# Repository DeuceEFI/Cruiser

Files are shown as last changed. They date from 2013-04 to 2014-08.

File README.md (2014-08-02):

# Cruiser Development Board for FreeEMS

JAG 8/2/2014 1422 EDT (GMT-0400)

### Introduction

The name "Cruiser" is loosely based on the SanDisk Cruzer Edge USB flash drive that was sitting in front of me while I was designing this development board.  This is intended to be a handy, portable, USB bus powered development board for Freescale MC9S12XDP512 firmware and software developers.

Please see forum.diyefi.org for the most up to date information and links for this project and all of the other aspects of the FreeEMS project.

### Goals

Core specs:

 * The least amount of parts to make a functional development board.
 * Freescale MC9S12XDP512MAL processor with 16MHz crystal.
 * FTDI USB (bus powered) communications (USB-A board edge connector).
 * Rx/Tx LEDs for USB communications troubleshooting.
 * Load/Run LED connected to Port A6.
 * Solder bridge pads for enabling LEDs.
 * Reset momentary switch.
 * Load momentary switch.
 * Port T0-3 inputs/outputs with 1k current limiting resistors.

PCB size is to be as small as possible and to be powered by the USB bus, to allow for easy transport for development work.  The current design is a 50mm x 50mm PCB (shaped like a key) which has an USB-A male connector.  There are solder bridge pads on the bottom layer to allow the LEDs to be connected or not, depending on whether the user would like the LEDs for troubleshooting or stealth.
 
### Status

This design has been tested and is considered to be a usable design.

I will update this status as work progresses.

#### Update 11/15/2012: The first 10 version 0.1-alpha PCBs have been ordered from seeedstudio Fusion PCB service for testing the design.

#### Update 8/2/2014: I now stock the 0.3-alpha PCBs and components, they can be ordered from http://www.coolefi.com

### Changes

Please send any changes that you make to Cruiser back upstream to Andy Goss' copy at https://github.com/DeuceEFI/Cruiser

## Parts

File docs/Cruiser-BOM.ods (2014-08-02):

Quantity | Reference | Value | Description | Manufacturer | Manufacturer Part # | Digikey Part # | Approximate Cost Each | Cost to Build
3 | C1,2,3 | 0.1uF | Ceramic Capacitor 0.1uF 50V 10% X7R 1206 | Kemet | C1206C104K5RACTU | 399-1249-1-ND | $0.10 | $0.30
7 | C4,5,6,7,8,9,10 | 0.22uF | Ceramic Capacitor 0.22uF 50V 10% X7R 1206 | Samsung Electro-Mechanics | CL31B224KBFNNNE | 1276-1106-1-ND | $0.05 | $0.35
1 | C11 | 10uF | Ceramic Capacitor 10uF 16V 10% X7R 1206 | Kemet | C1206C106K4RACTU | 399-3525-1-ND | $0.40 | $0.40
2 | C12,13 | 18pF | Ceramic Capacitor 18pF 50V 10% NP0 1206 | Kemet | C1206C180J5GACTU | 399-1195-1-ND | $0.13 | $0.26
1 | C14 | 6.8nF | Ceramic Capacitor 6800pF 100V 5% X7R SMD 1206 | AVX | 12061C682JAT2A | 478-3794-1-ND | $0.27 | $0.27
1 | C15 | 680pF | Ceramic Capacitor 680pF 630V 5% NP0 1206 | TDK Corporation | C3216C0G2J681J085AA | 445-2341-1-ND | $0.28 | $0.28
1 | D2 | Green LED | LED 568NM Green SMD 1206 | OSRAM Opto Semiconductors | LG N971-KN-1 | 475-1407-1-ND | $0.09 | $0.09
1 | D3 | Red LED | LED 645NM Red SMD 1206 | OSRAM Opto Semiconductors | LH N974-KN-1 | 475-1416-1-ND | $0.09 | $0.09
1 | D1 | Yellow LED | LED 587NM Yellow SMD 1206 | OSRAM Opto Semiconductors | LY N971-HL-1 | 475-2556-1-ND | $0.11 | $0.11
1 | L1 | 40 | Ferrite 1.5A 40 Ohm 0805 SMD | Laird-Signal Integrity Products | MI0805K400R-10 | 240-2389-1-ND | $0.10 | $0.10
6 | R1,2,3,4,5,6 | 10k | Resistor 10K Ohm 1/4W 1% 1206 SMD | Bourns | CR1206-FX-1002ELF | CR1206-FX-1002ELFCT-ND | $0.02 | $0.12
8 | R7,8,11,12,13,14,15,16 | 1k | Resistor 1.0K Ohm 1/4W 5% 1206 SMD | Panasonic Electronic Components | ERJ-8GEYJ102V | P1.0KECT-ND | $0.02 | $0.19
1 | R10 | 3.3k | Resistor 3.30K Ohm 1/4W 1% 1206 SMD | Yageo | RC1206FR-073K3L | 311-3.30KFRCT-ND | $0.03 | $0.03
2 | SW1,2 | Load,Reset | Tactile Switch SPST-NO 0.05A 12V | APEM Components | MJTP1230 | 679-2428-ND | $0.10 | $0.20
1 | U1 | FT232RL | IC USB FS Serial UART 28-SSOP | FTDI | FT232RL-REEL | 768-1007-1-ND | $4.05 | $4.05
1 | U2 | MC9S12XDP512 | IC MCU 512K Flash 112-LQFP | Freescale | MC9S12XDP512MAL | MC9S12XDP512MAL-ND | $23.51 | $0.00
1 | X1 | 16MHz | Crystal 16.000MHz 18pF 4-SMD | CTS-Frequency Controls | 405C35D16M00000 | CTX820CT-ND | $1.16 | $1.16
1 | USB-A |  | USB-A Male Connector | CNC Tech | 1001-010-01001 | 1175-1007-ND | $0.65 | $0.65
1 | PCB |  | Cruiser Printed Circuit Board | SeeedStudio Fusion PCB |  | Approximate Cost |  | $1.40
 |  |  |  |  |  | Total Cost To Build |  | $10.05

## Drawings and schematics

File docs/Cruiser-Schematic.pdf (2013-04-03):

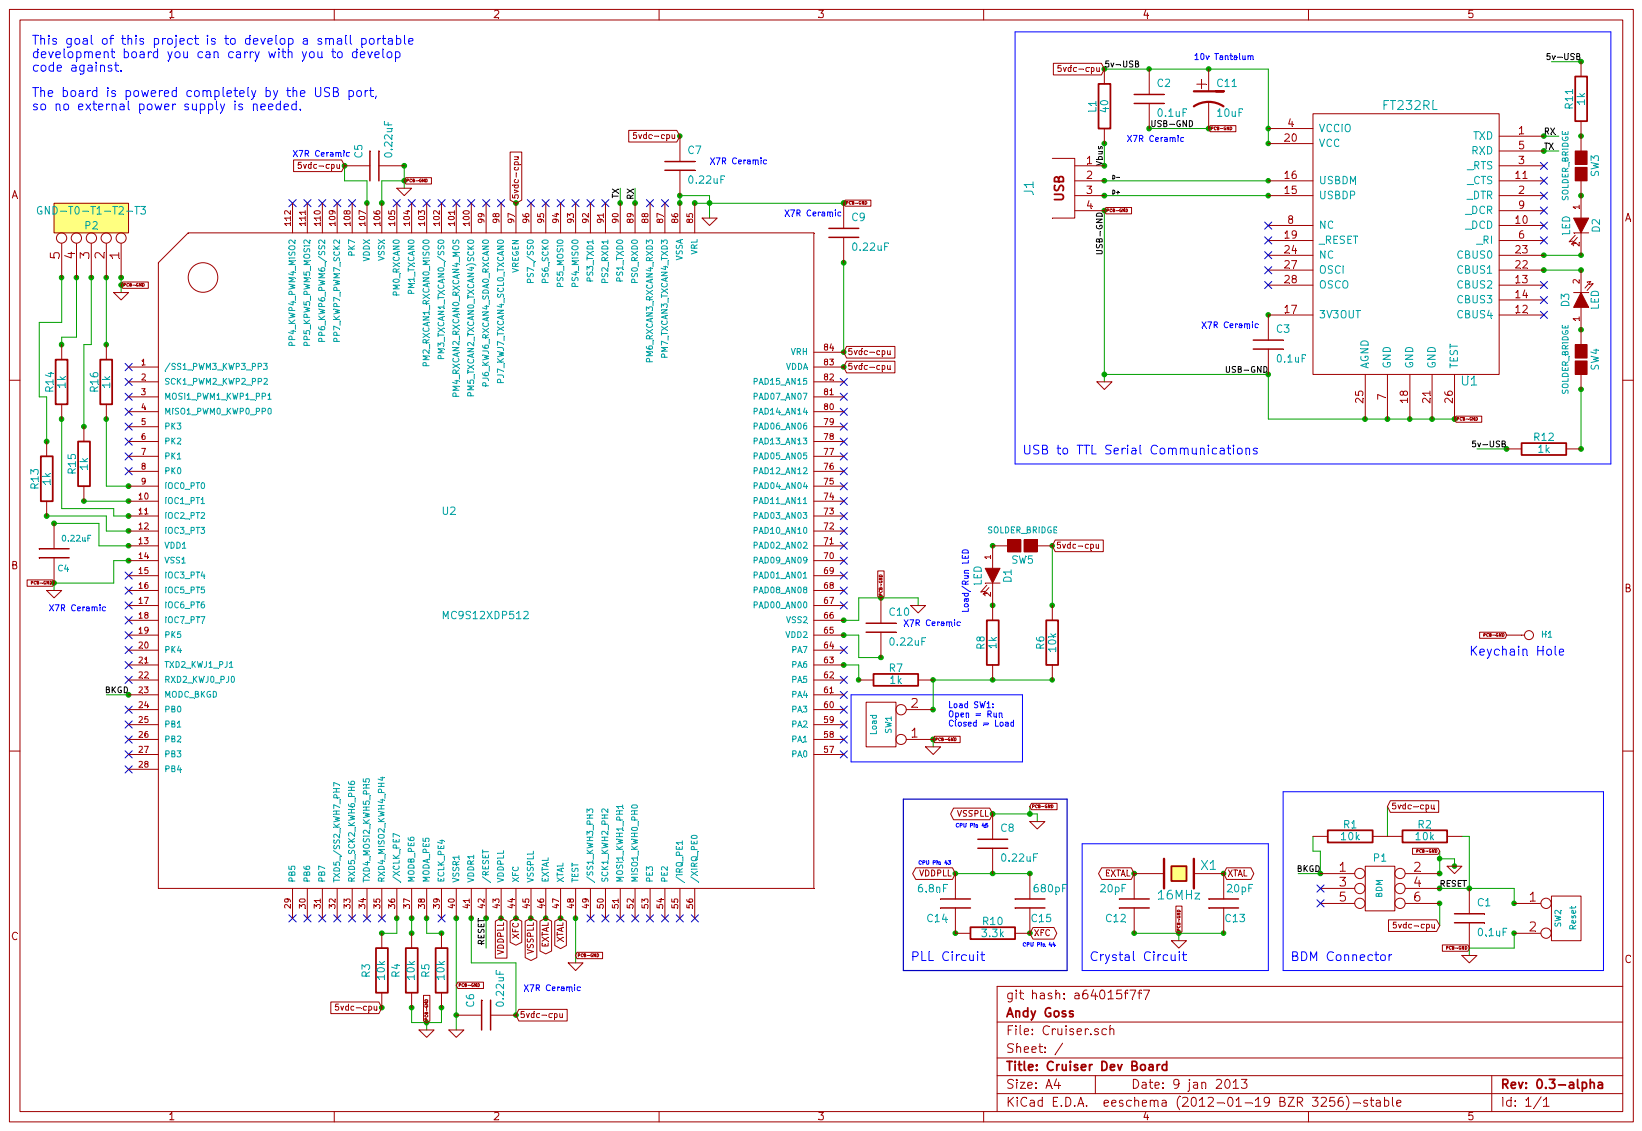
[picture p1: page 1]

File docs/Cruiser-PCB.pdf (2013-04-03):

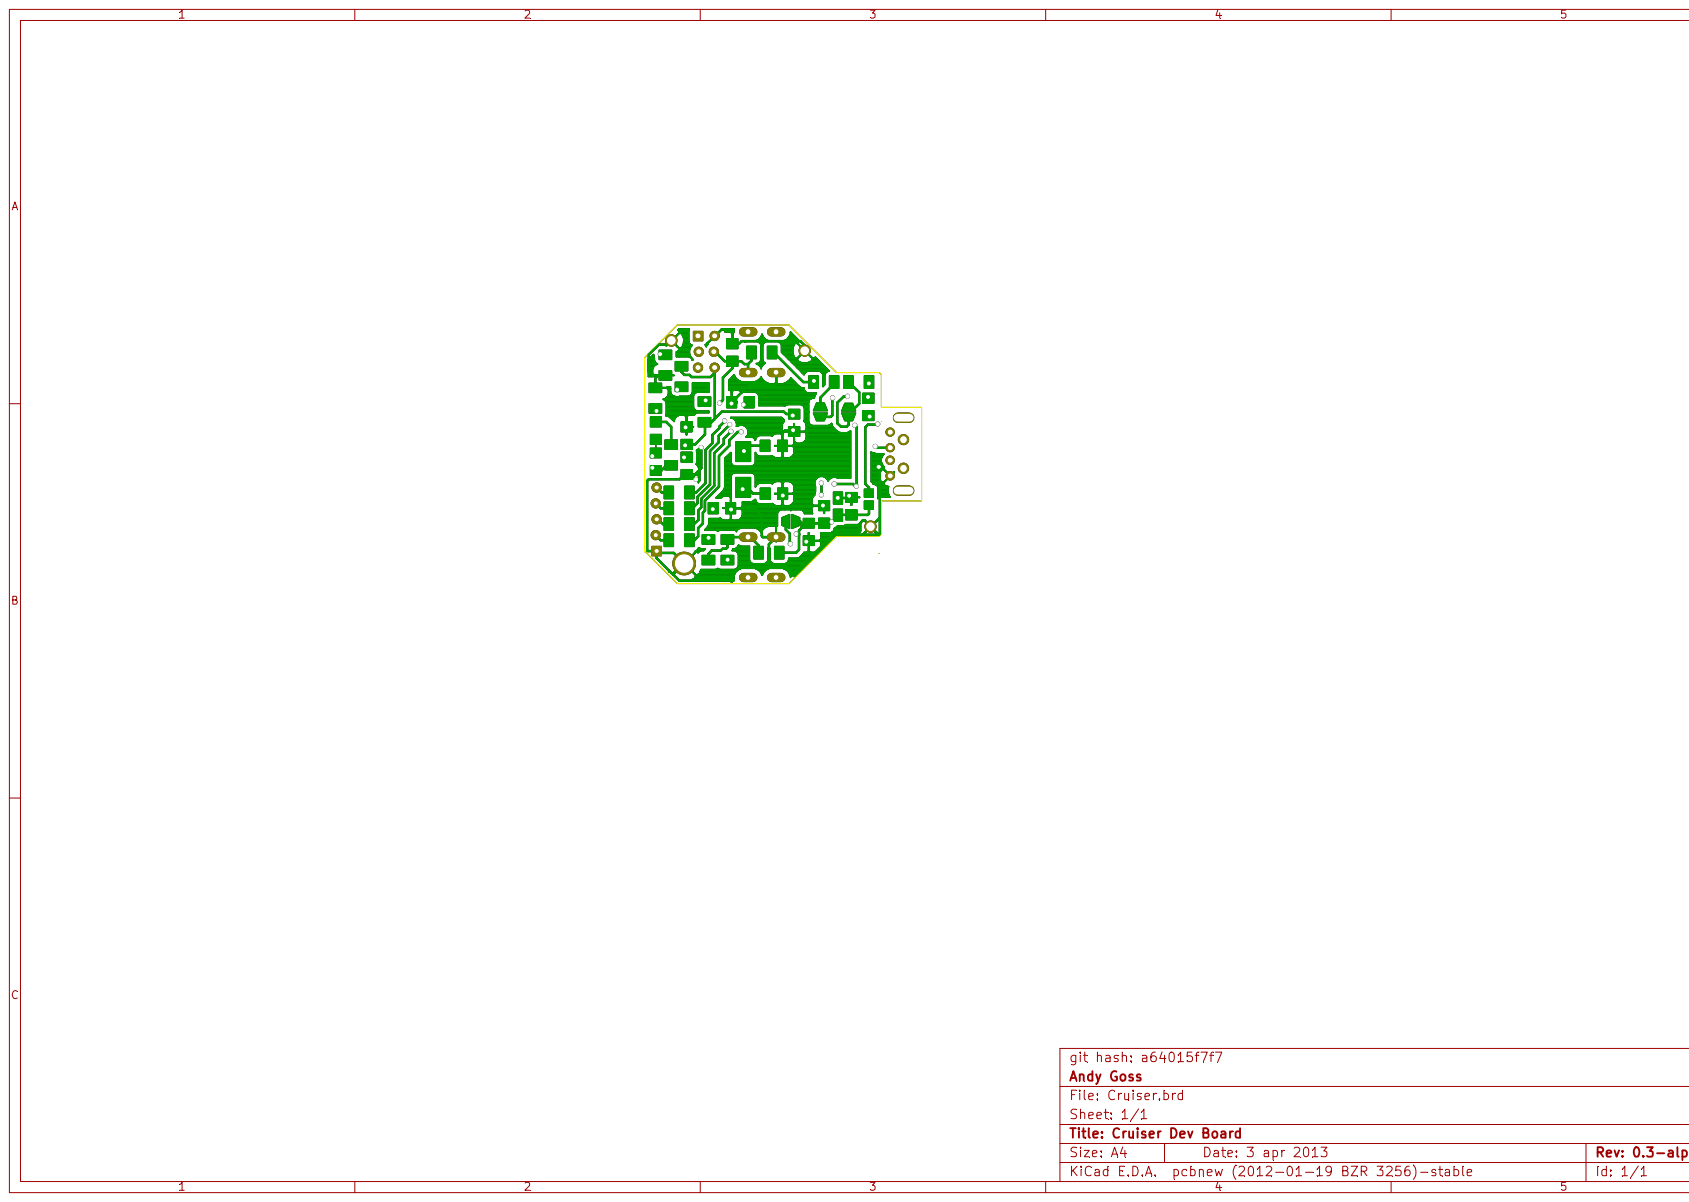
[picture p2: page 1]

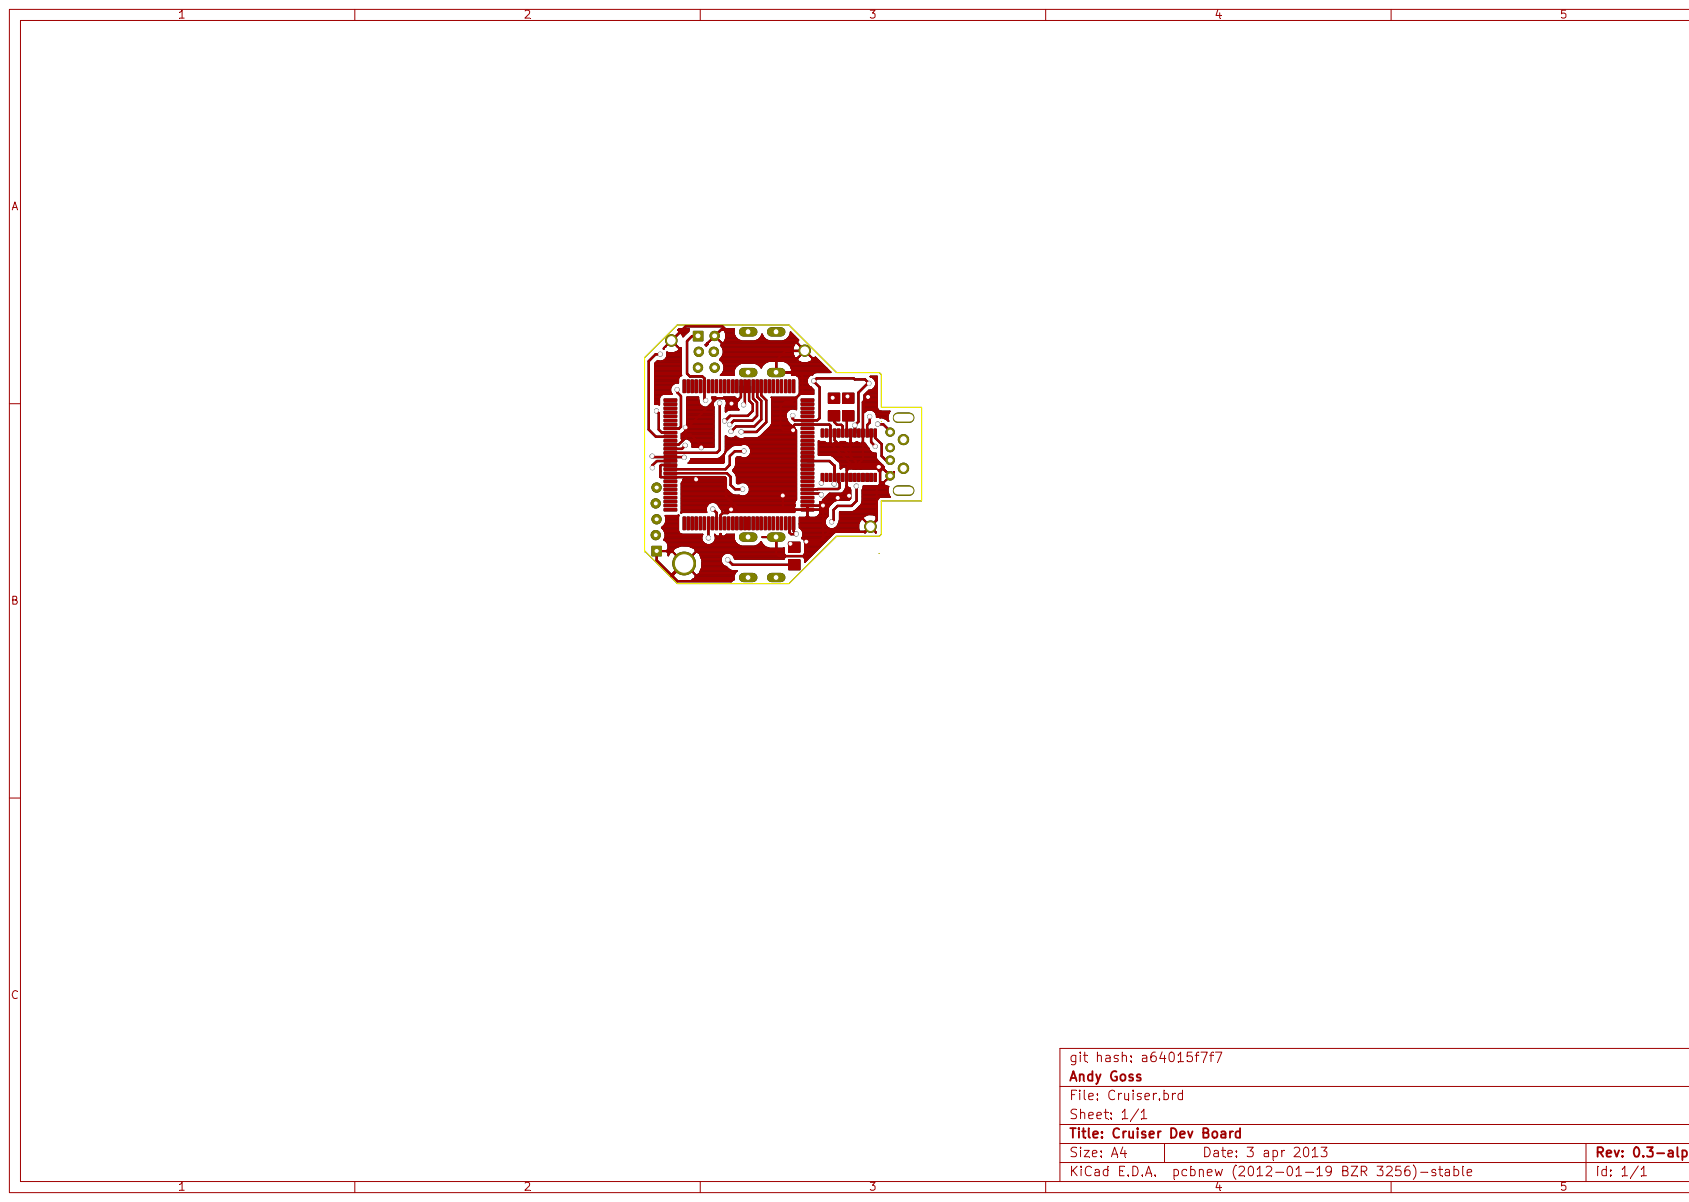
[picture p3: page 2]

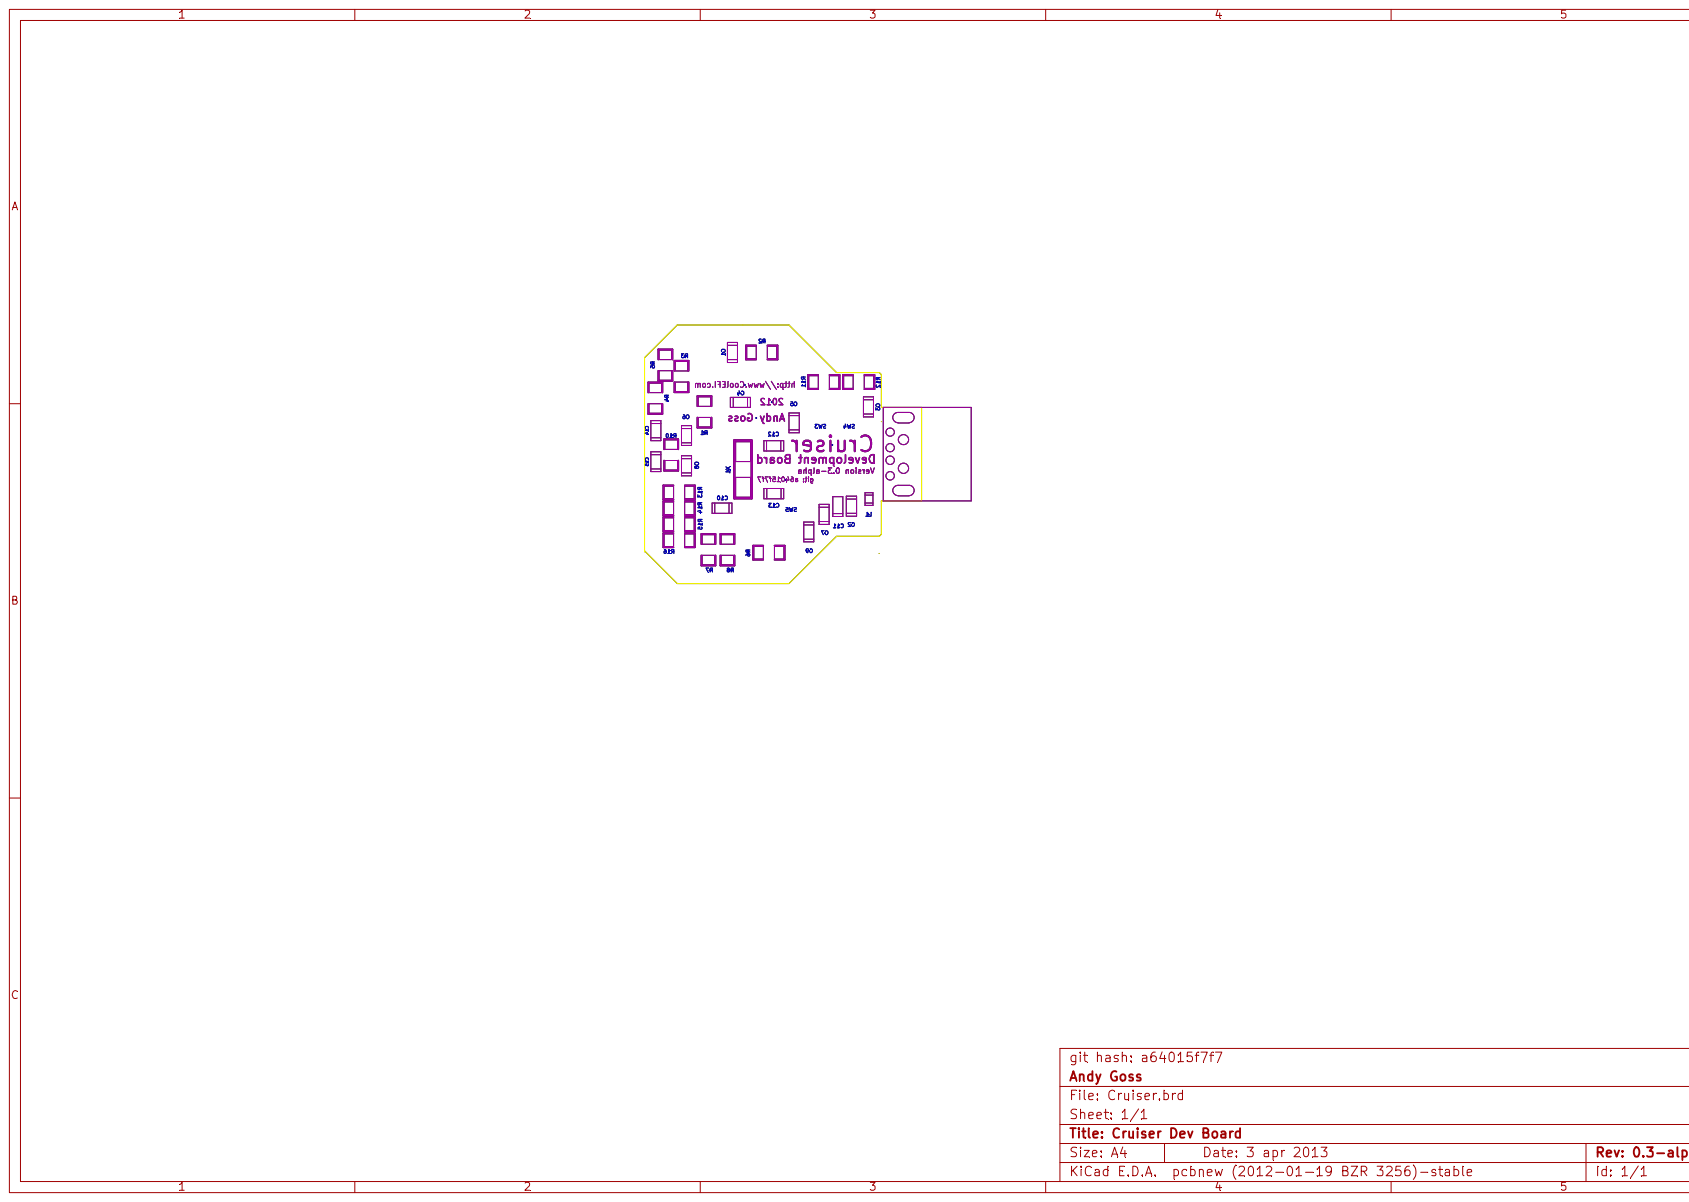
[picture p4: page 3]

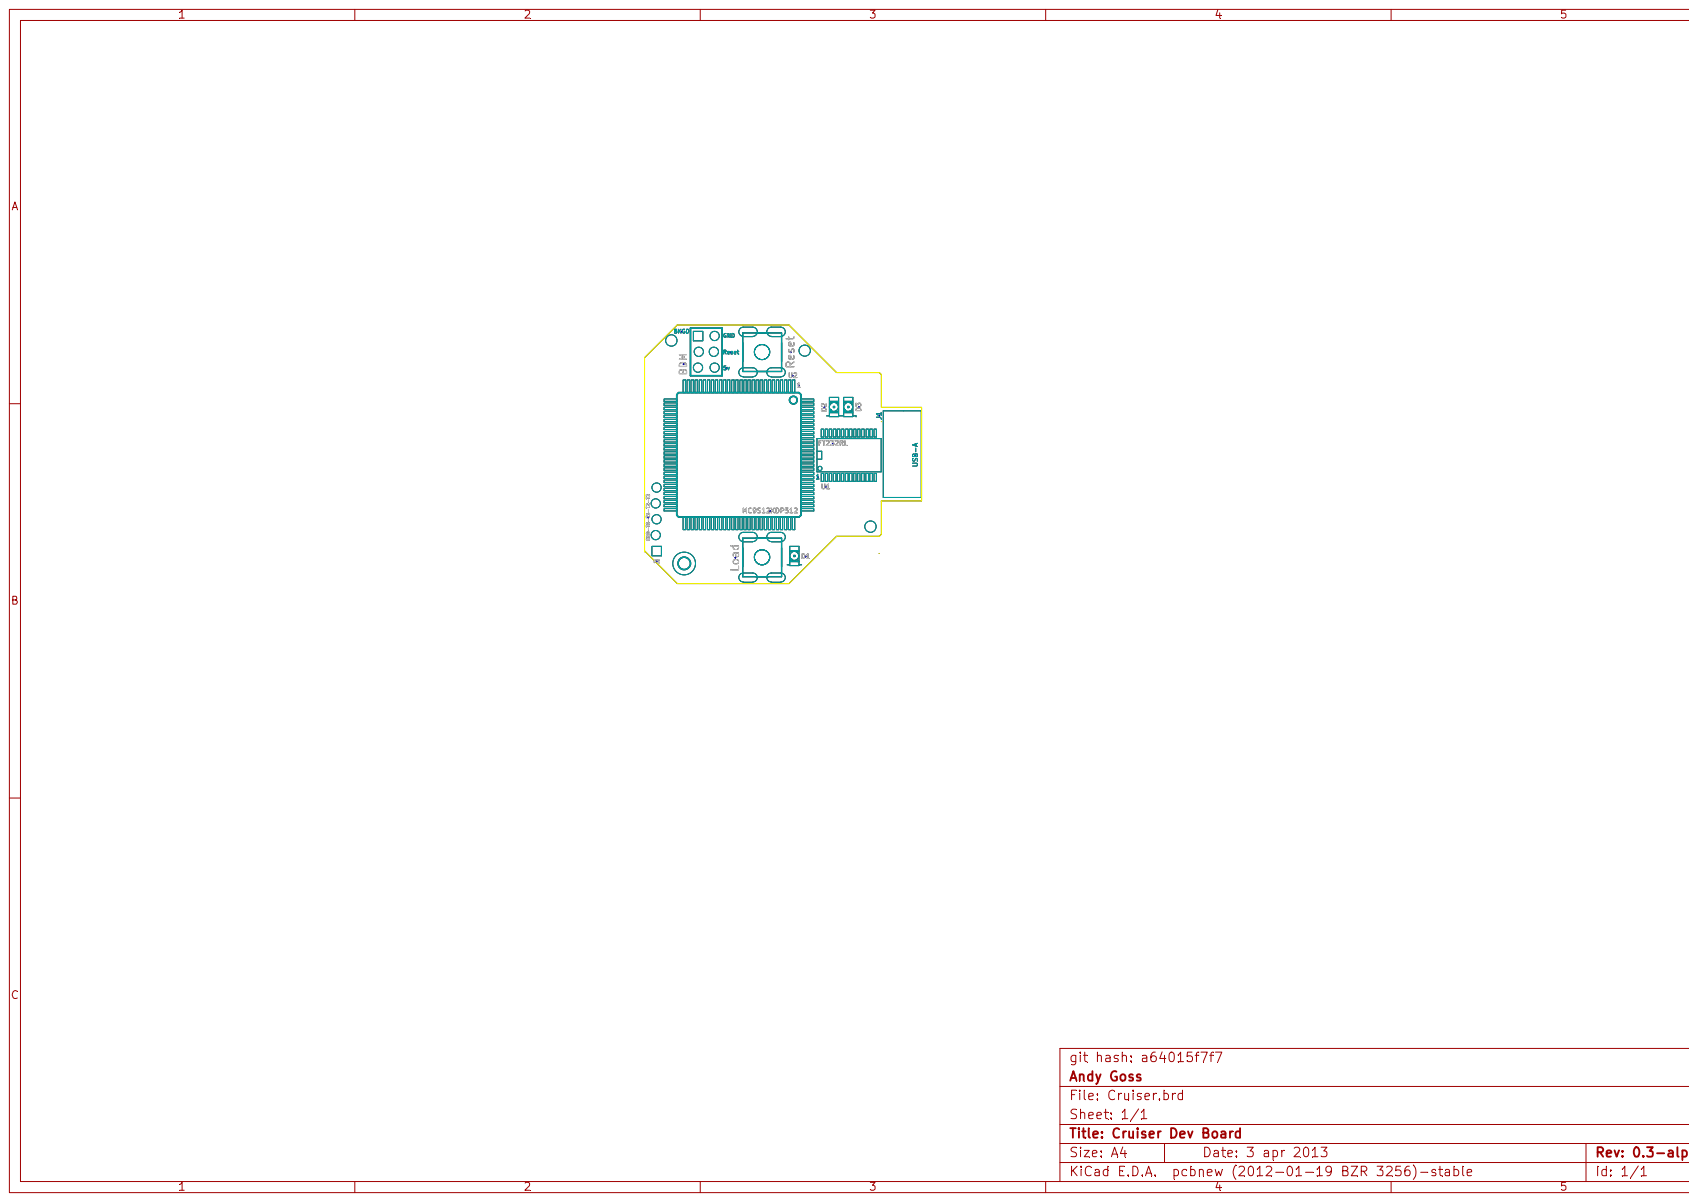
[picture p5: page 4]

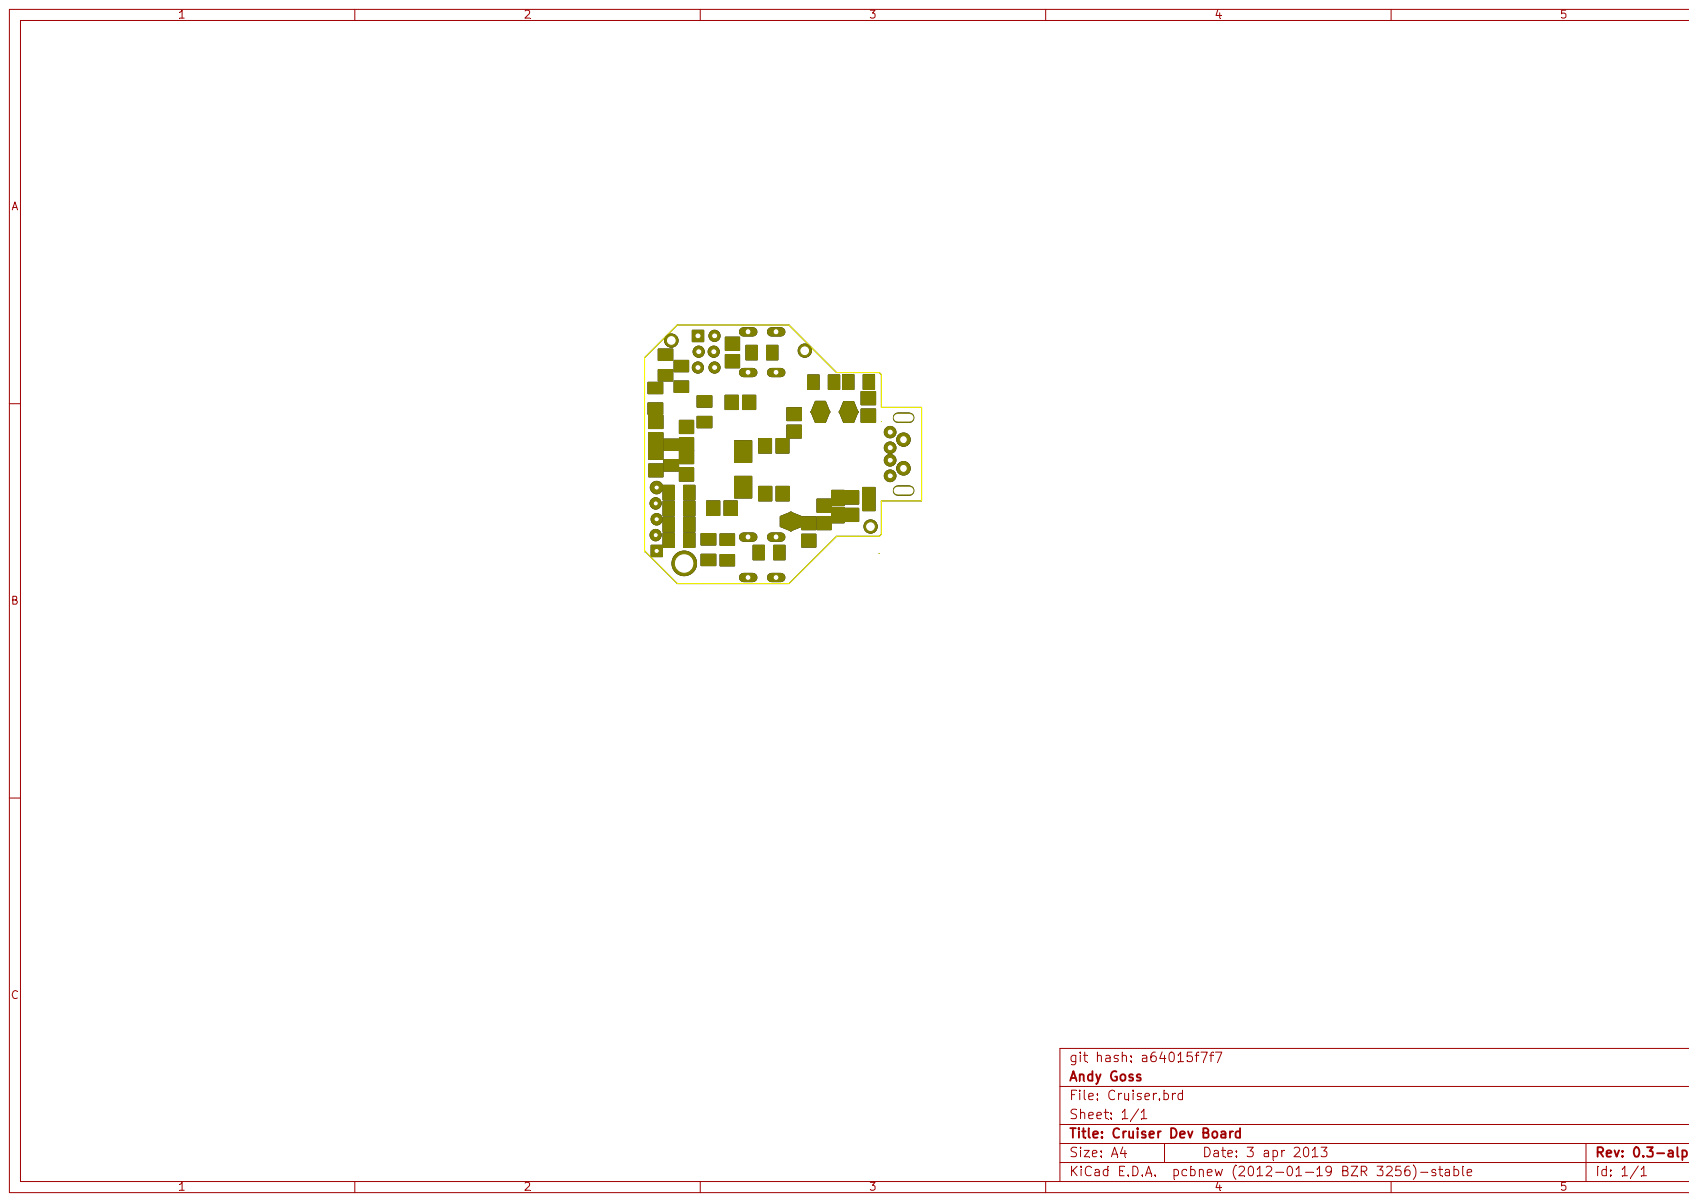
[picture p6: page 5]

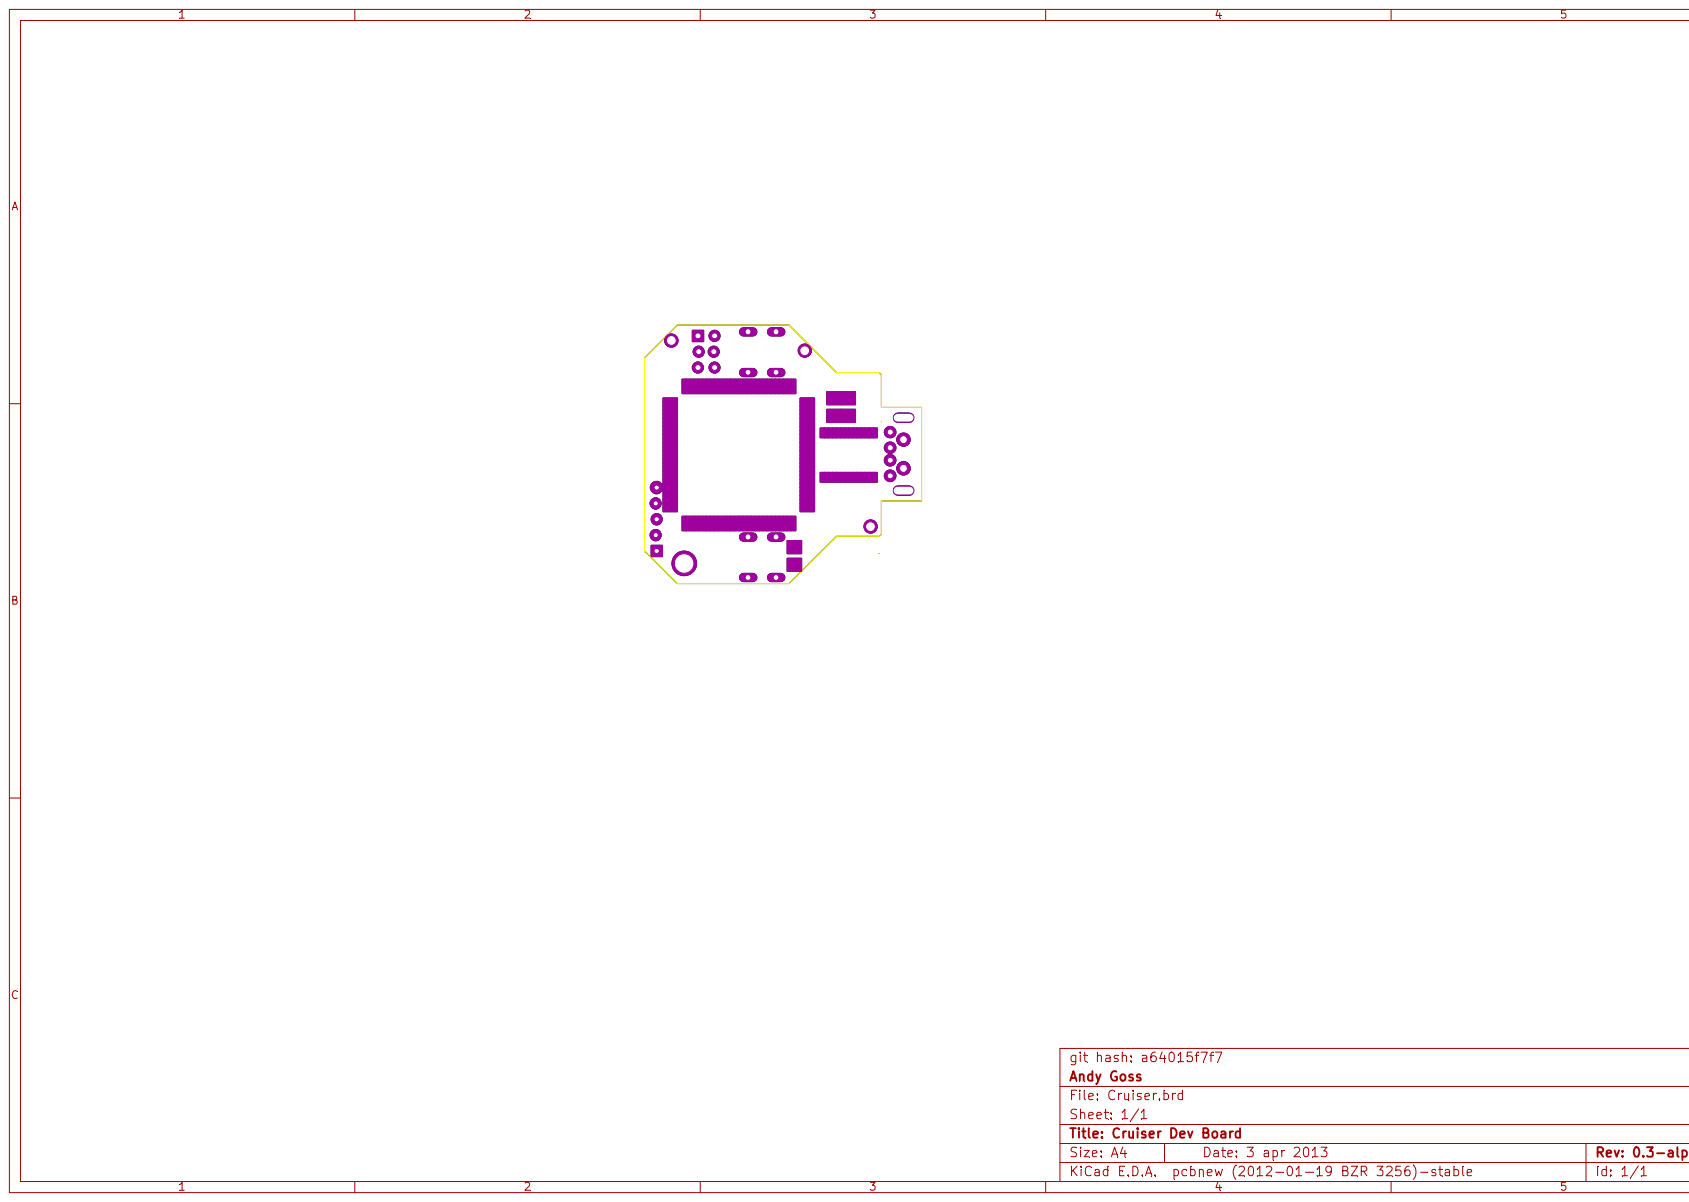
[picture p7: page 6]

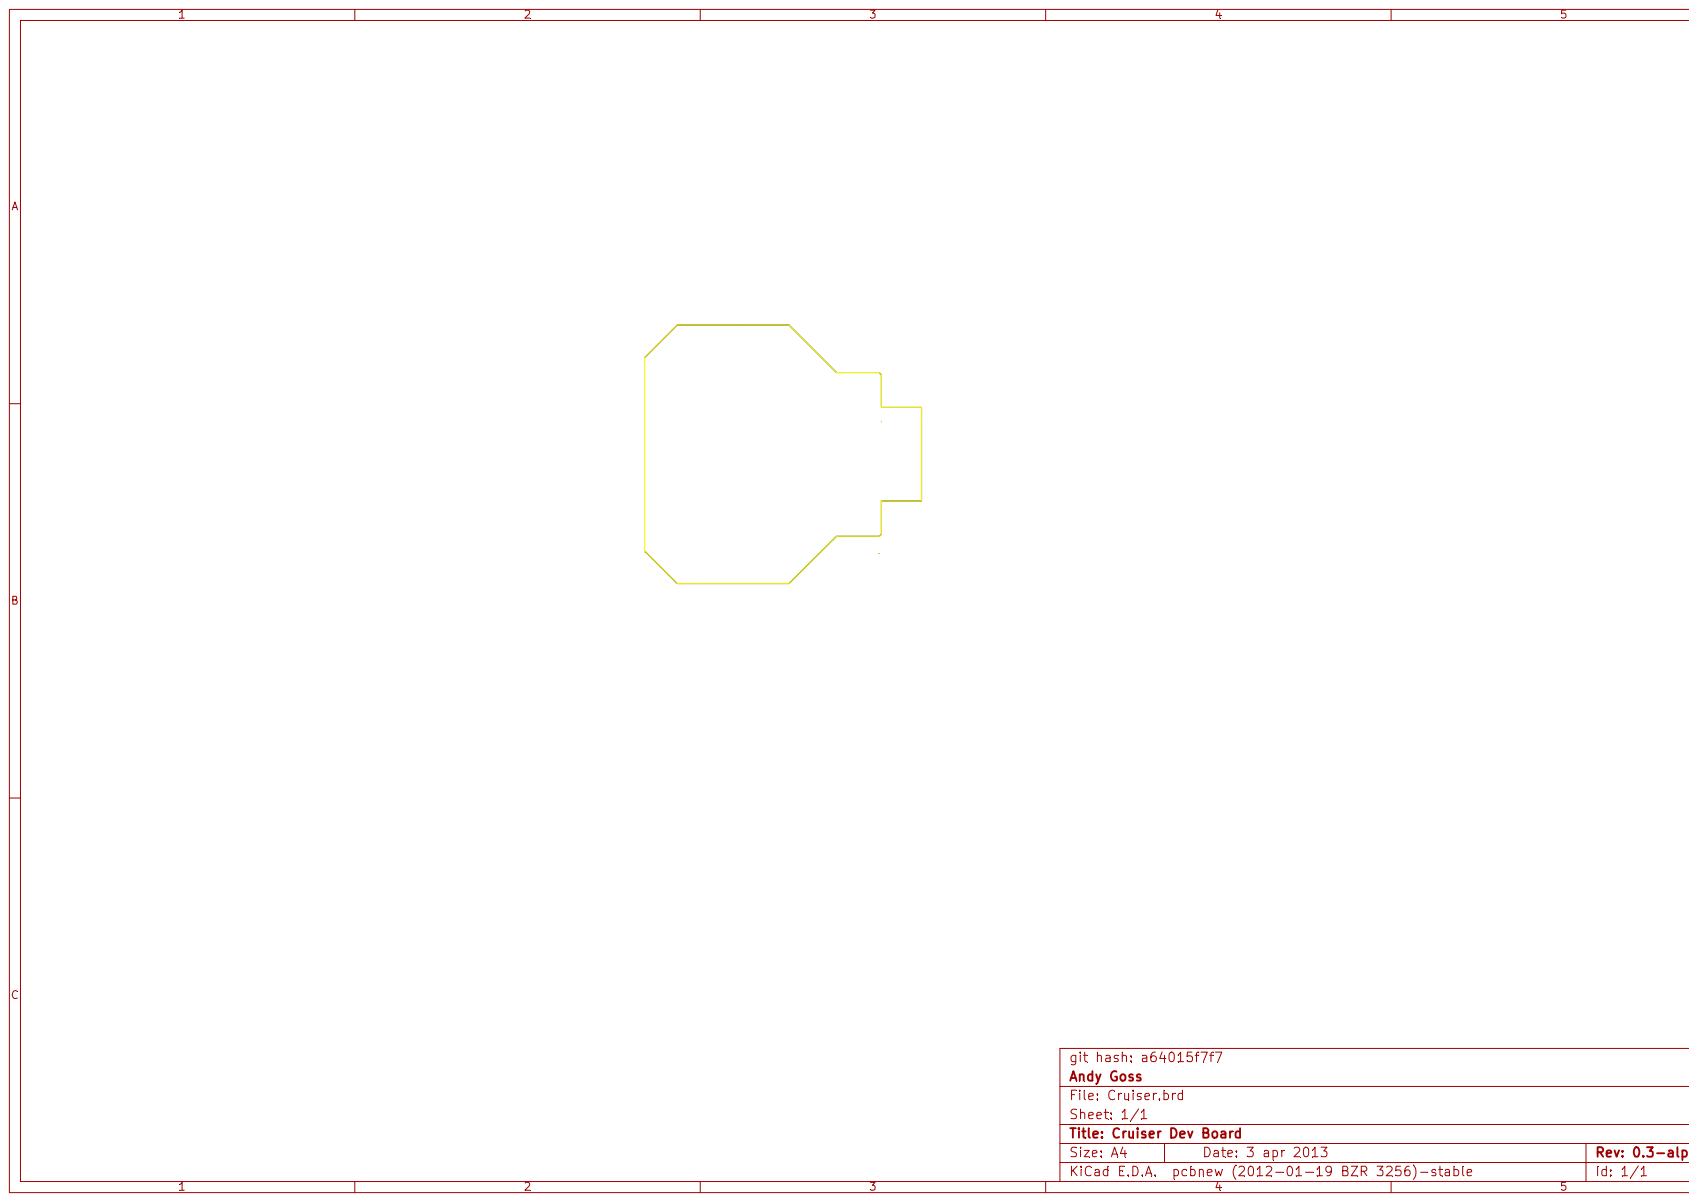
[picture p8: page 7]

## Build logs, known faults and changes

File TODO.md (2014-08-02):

# To Do List

## JAG 08/02/2014 1427 EDT (GMT-0400)

### Things left to change For Cruiser 0.4-alpha PCB based on what has been learned from 0.3-alpha PCB:

* Stagger BDM pads for a nice tight fit.
* Mark LED anode more clearly on the silkscreen so it can be seen while placing SMD LED (green dot in lens) on the board.

----------
### TODO 0.4-alpha Changes Completed:

* Revised BOM to show different color LEDs, yellow for Port A6 (D1), red for Tx (D3) and green for Rx (D2). - DONE 08/02/2014
* Revised BOM to correct C14 to be 6800pF (6.8nF) to match the 6.8nF shown in the schematic. - DONE 08/02/0214
* Added RX/TX to silkscreen next to FTDI LEDs. - DONE 05/15/2013
* Added CEL to silkscreen next to D1. - DONE 05/15/2013
* Decreased BDM pad holes from 0.0394" to 0.0350". - DONE 05/15/2013

----------

* Change T0-T3 wire connections to 0.100" pitch header.
* Widen all traces to the same width as the MCU pads, the default trace size is VERY tiny.
* Make the USB-A end 12mm wide, it is too narrow.
* Add 1.6mm plated through holes on the beveled edges to allow stacking multiple Cruisers together.
* Make the USB-A pads wider.
* Make the USB-A end 12mm wide, it is too narrow.
* Add D shaped pads to allow LEDs to be soldered on/off.
* Change from USB-A PCB traces to USB-A shielded connector.

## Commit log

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2012-11-03 Started laying out PCB by placing some of the larger components.
    [Cruiser.brd]
2012-11-03 Started laying out 25mm x 50mm PCB design.
    [Cruiser.brd]
2012-11-04 preliminary 25mm x 50mm rectangular PCB layout completed.
    [Cruiser.brd, Cruiser.sch]
2012-11-04 Updated git hash on PCB to 0dbdc55951 marking the first version of the PCB.
    [Cruiser.brd]
2012-11-04 Added Version 0.1-alpha to silkscreen on bottom side.
    [Cruiser.brd]
2012-11-04 Updated git hash on PCB to 0dac5ede2d after adding Verion 0.1-alpha to the silkscreen on the bottom side.
    [Cruiser.brd]
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2012-11-04 Condensed the schematic to one sheet for easier reading.
    [Cruiser.sch, ft232.sch]
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2012-11-04 Deleted non-essential capacitors and created a new PCB layout that is less than 50mm x 50mm (1.969" x 1.969") which looks like a key.
    [Cruiser.brd, Cruiser.sch]
2012-11-04 Updated git hash to 9b4c4c8ada on the schematic and the PCB.
    [Cruiser.brd, Cruiser.sch]
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2012-11-04 Made USB traces wider from the plug area, removed the ground plane from the plug area and moved Vbus via away from plug area.
    [Cruiser.brd]
2012-11-04 Increased the size of the Vbus, 5v-USB and USB-GND trace sizes, resized the crystal footprint.
    [Cruiser.brd]
2012-11-04 Staggered the BDM connector pads in the KiCAD footprint and on the PCB.
    [Cruiser.brd]
2012-11-04 Updated git hash on the schematics and PCB to 3f99b6f451
    [Cruiser.brd, Cruiser.sch]
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2012-11-05 Moved PLL, Crystal and BDM circuits up away from the title block.
    [Cruiser.sch]
2012-11-05 Updated PDF files after moving PLL, Crystal and BDM circuits away from the title block, updated git hash to 42168aa2bd.
    [Cruiser.brd, Cruiser.sch]
2012-11-08 Added port T2 and T3 outputs and 1k resistors to schematic and PCB to be able to use it as a FredStim.
    [Cruiser.brd, Cruiser.sch]
2012-11-08 Updated git hash on Schematic and PCB to 3bd36c0e69.
    [Cruiser.brd, Cruiser.sch]
2012-11-08 Updated BOM to reflect the 2 1k resistors that were added.
    [Cruiser-BOM.ods]
2012-11-08 Updated schematics, PCB and BOM to have L1 instead of R9.
    [Cruiser-BOM.ods, Cruiser.brd, Cruiser.sch]
2012-11-08 Updated git hash on Schematics and PCB to dba011e793
    [Cruiser.brd, Cruiser.sch]
2012-11-09 Corrected Vbus trace and 5vdc-cpu trace that were disconnected after changing from R9 to L1.
    [Cruiser.brd]
2012-11-09 Updated git hash on Schematic and PCB to 6a6c438f88 after correcting Vbus and 5vdc-cpu traces.
    [Cruiser.brd, Cruiser.sch]
2012-11-12 Added T0 and T1 outputs and their 1k resistors.
    [Cruiser-BOM.ods, Cruiser.brd, Cruiser.sch]
2012-11-12 Updated git hash on Schematic and PCB to 849d4d2d00 after adding the T0 and T1 outputs.
    [Cruiser.brd, Cruiser.sch]
2012-11-12 Added vias to the ground plane from one side of the board to the other and added more trace around the "Hole" on both sides.
    [Cruiser.brd]
2012-11-12 Updated git hash on Schematic and PCB to b8ef8dcb86 after ground plane changes.
    [Cruiser.brd, Cruiser.sch]
2012-11-13 Added Gerber files that were used for the v0.1-alpha boards to the repository.
    [Cruiser.drl, Cruiser.gbl, Cruiser.gbo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]
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2012-11-15 Updated README.md to show Port T0-2 outputs and the seeedstudio PCB order.
    [Cruiser-BOM.ods]
2012-12-05 Generated correct Gerber files for production as the first files I had sent to SeeedStudio were from an older hash.
    [Cruiser.drl, Cruiser.gbl, Cruiser.gbo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]
2012-12-06 Corrected switch module pinout and USB-A-Traces pinout after testing first prototype.
    [Cruiser.brd]
2012-12-06 Updated version to 0.2-alpha after switch and USB-A-Traces changes.
    [Cruiser.brd, Cruiser.sch]
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2012-12-19 Added 0.100" header solder pads for Port T0-3 plus GND
    [Cruiser-BOM.ods, Cruiser.brd, Cruiser.sch]
2012-12-19 Updated git hash on schematics and PCB to 9b5852938f
    [Cruiser.brd, Cruiser.sch]
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2013-01-09 Widened all traces to be 0.0150" wide, which is the same as the MCU/FTDI pad width.
    [Cruiser-BOM.ods, Cruiser.brd]
2013-01-09 Widened the USB-A PCB edge width to 12mm and changed measurments to millimeters.
    [Cruiser.brd]
2013-01-09 Added 3 - 1.6mm holes to allow stacking multiple Cruisers together.
    [Cruiser.brd]
2013-01-09 Updated git hash on PCB and Schematics to 7c27a10510 after making the changes.
    [Cruiser.brd, Cruiser.sch]
2013-01-09 Added solder bridge "switches" to allow the LEDs to be turned ON/OFF.
    [Cruiser.brd, Cruiser.sch]
2013-01-09 Updated git hash on PCB and Schematics to ca961ae3e7 after adding LED "switches".
    [Cruiser.brd, Cruiser.sch]
2013-01-09 Changed to USB-A shielded connector instead of USB-A PCB traces to allow use of 1.6mm PCB material instead of 2mm PCB material.
    [Cruiser.brd]
2013-01-09 Routed traces to USB-A connector and filled in ground plane.
    [Cruiser.brd]
2013-01-09 Updated git hash to 25275c1c5d on PCB and Schematics after changing out the USB-A traces for a shielded USB-A connector.
    [Cruiser.brd, Cruiser.sch]
2013-04-02 Removed PCB GND connections to USB-A shield connections plated through holes.
    [Cruiser.brd]
2013-04-02 Updated git hash to a64015f7f7 after correcting USB-A connector shield pads.
    [Cruiser.brd]
2013-04-03 Updated BOM, updated hash on drawings and generated Gerber files.
    [Cruiser-BOM.ods, Cruiser.brd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]
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2013-05-15 Added RX/TX to silkscreen next to FTDI LEDs. Added CEL to silkscreen next to D1.
    [Cruiser.brd]
2013-05-15 Decreased BDM pad holes from 0.0394" to 0.0350".
    [Cruiser.brd]
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2013-06-12 Updated BOM with non-automotive rated capacitors and resistors.
    [Cruiser-BOM.ods]
2014-08-02 Revised BOM to show different color LEDs, yellow for Port A6 (D1), red for Tx (D3) and green for Rx (D2). Revised BOM to correct C14 to be 6800pF (6.8nF) to match the 6.8nF shown in the schematic.
    [Cruiser-BOM.ods, Cruiser.brd, Cruiser.dsn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]
